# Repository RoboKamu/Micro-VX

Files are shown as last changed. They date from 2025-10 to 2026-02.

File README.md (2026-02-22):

<h1 align="center"> Micro-VX: Mini Audio Visualizer </h1>

<div align="center">
<i> Small portable STM32L4 based audio wave and FFT visualizer from electret microphone. This project started as an experiment to design my first PCB and explore the STM32L4 low-power MCU family. </i>
</div>

---

> This repository includes an extra project on the same board. The accelerometer visualization. That project was for expirementing with the module for future use. The main purpose for the board is for it to be used with the microphone, however a PCB error ment it had to be modified after assembly.
>

> Demo for expirimental Accelerometer Visualization: Github Video Link 
>
> Demo for FFT and Auido Wave Visualization: [Youtube Video Link](https://www.youtube.com/watch?v=JHZs5dUxs48)

<p align="center">
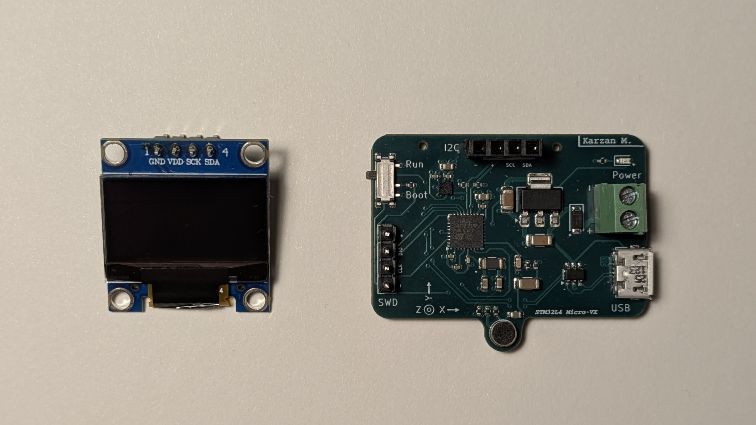
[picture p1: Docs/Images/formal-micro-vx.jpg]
Micro-VX board and OLED module
  
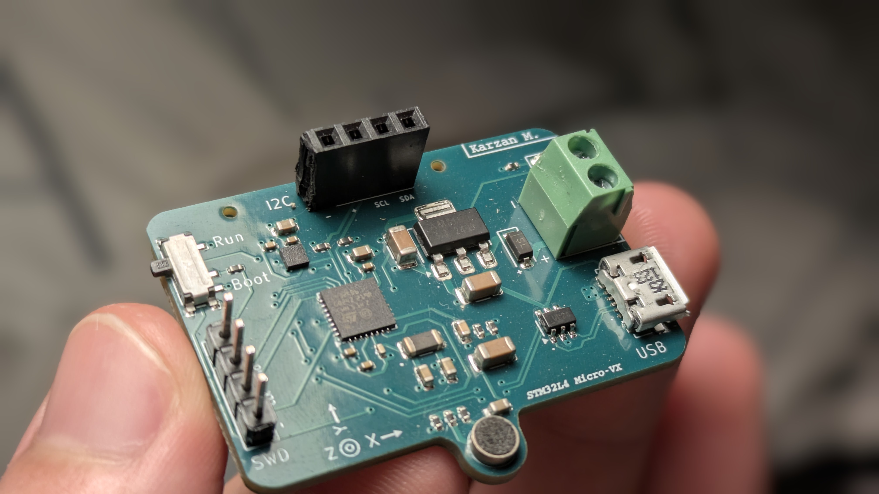
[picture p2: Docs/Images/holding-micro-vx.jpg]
Close-up of the assembled STM32L4 Micro-VX board
  
</p>

---

### 1. Project structure

#### 1.1 Hardware

All Kicad source files for Schematic and PCB files are in the hardware folder. Also including Gerber files and footprint placement (assembly) for direct manufacturing, in this case JLCPCB. 

There are 2 versions of the PCB, with one being modified after assembly.

* **Accelerometer visualization:** 
Original PCB according to the schematic. Utilizing the Accelerometer (3-axis LIS2DW12) and I2C pin headers for OLED display (SSD1306).

* **Audio analyzer:**
Modified after assembly (refer to hardware folder). The PCB used for the audio analysis with electret microphone (B4013AM423-093). Also utilizes the I2C pin headers for OLED display (SSD1306) and a mechanical switch to change program state. 

#### 1.2 Firmware

In the firmware folder you will see 2 projects: 

* **The STM32L4-LIS2DW12-Visual project in the STM32L4-Accelerometer-Visual folder:**
Visualizer for the cheap accelerometer I added to the PCB. The program just shows the X, Y and Z axis as well as temperature. Another detail is to measure VDDA, this is very useful for sampling with ADC on battery powered devices. Ensuring accurate scaling. 

* **STM32L4-FW :**
The main project is this audio wave and FFT visualizer. Depending on the mechanical switch state (read from EXTI callback) it can either be showing continous audio wave or the FFT representation of it. Includes TIMER2 peripheral for triggering ADC to sample microphone, DMA double buffering, and I2C protocol for OLED display. The MCU was programmed with a ST-LINK V2, developed in STM32cubeIDE with HAL, and used the ARM cmsis library for DSP applications. 

### 2. Hardware Architecture
The PCB includes ESD protection and reverse polarity protection. Safe to use even if both battery and USB is connected because of the schottcky diode "OR", and the onboard LDO ensures a stable voltage for the STM32.  

Refer to the hardware folder for more specific information about the post assembly modification. 

The STM32L4 was chosen because it is from the low power series and also includes FPU and DSP. Not much flash memory is needed here so the 32 KB flash size was chosen. 

### 3. Firmware Architecture

#### 3.1 STM32L4-FW 

The firmware is rather simple. Timer2 TRGO initiate a conversion with a sample rate of 50 kHz. The ADC uses 8x oversampling with 1 bit shift to compensate low gain on hardware. DMA double buffer is used so wave visualizer does not have to wait for the whole fft buffer fill up and instead waits for the halv-transfer-complete flag. The FFT uses the ARM CMSIS library and all visual functionality in this project is scaled to the OLED.

Improvements could be made in terms of optimization and scaling, but that is outside the scope of this project.  

#### 3.2 STM32L4-LIS2DW12-Visual project 
Timer 2 triggers ADC injected group conversion, the callback function then stores the raw ADC value to a variable and sets a data ready flag

Timer 15 triggers normal ADC conversion, the callback function then stores the raw ADC value to a variable and sets a data ready flag

VDDA conversion just uses the last non zero value to calculate the voltage based on the formula from the datasheet. 

For the accelerometer the Data-Ready interrupt pin is connected to EXTI pin on microcontroller, when state changes on the pin the microcontroller notes this with a flag to later use in the superloop. 

### 4. Future improvements
This project was more of a practise so no real futher improvements are scheduled. One critical mistake that was overlooked was the usage of the microphone. The schematic PDF in the hardware folder shows no usage of preamp stage, this led to a bad resolution being sampled. For the PCB routing there are also obvious improvements to be made, but that will not be noted here. Below is an example of a improved schematic. The microphone preamp stage was validated via LTSpice simulation.

[revised-sch.pdf](https://github.com/user-attachments/files/25467140/revised-sch.pdf)

revised-sch

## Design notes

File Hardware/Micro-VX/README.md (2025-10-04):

Some revision has been made to the PCB. 

The PCB is based on the original schematic for microphone. This works correctly with the Accelerometer project, however, not with the audio analyzer. For the latter, a resistor has to be desoldered and another added. This is mentioned in the microphone section in the schematic. 

Below is an image showing the crude modification to the left, and the original PCBA to the right.

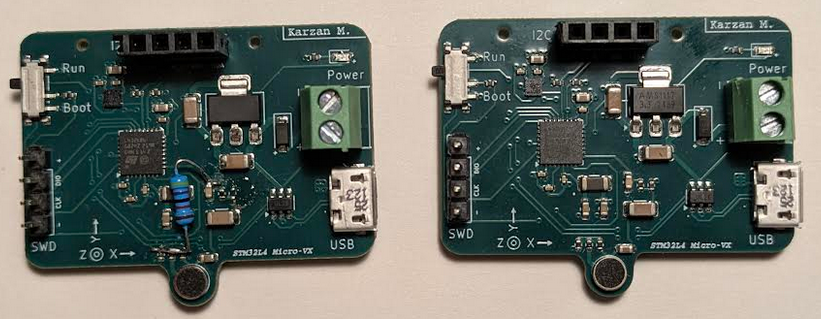
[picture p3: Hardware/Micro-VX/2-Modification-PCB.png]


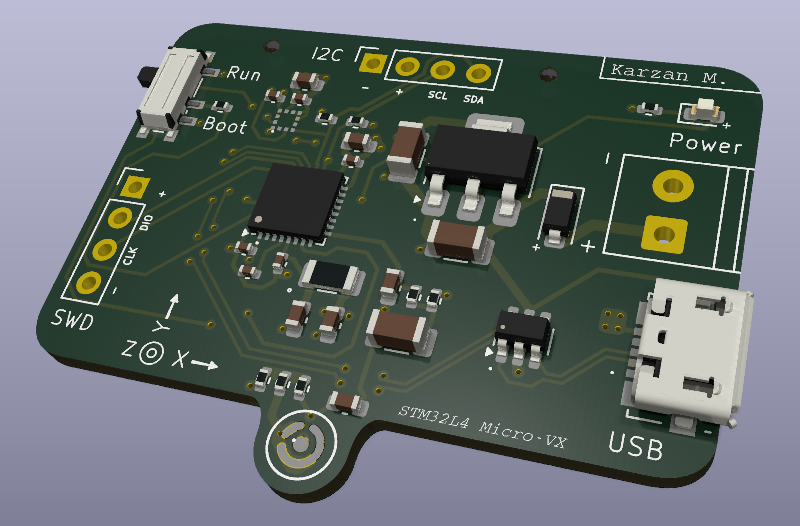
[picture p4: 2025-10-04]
Hardware/Micro-VX/1-Micro-VX.png

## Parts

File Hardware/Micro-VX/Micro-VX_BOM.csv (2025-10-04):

Reference | Qty | Value | Footprint | LCSC Part #
C1,C2,C7,C13,C14 | 5 | 100n | Capacitor_SMD:C_0402_1005Metric | C1525
C3,C12,C15 | 3 | 10u | Capacitor_SMD:C_0603_1608Metric | C19702
C4 | 1 | 10n | Capacitor_SMD:C_0402_1005Metric | C15195
C5,C6 | 2 | 1u | Capacitor_SMD:C_0603_1608Metric | C15849
C8,C9,C11 | 3 | 22u | Capacitor_SMD:C_1206_3216Metric | C12891
C10 | 1 | 22n | Capacitor_SMD:C_0603_1608Metric | C21122
D1 | 1 | LED | LED_SMD:LED_0603_1608Metric | C2286
D2 | 1 | D_Schottky | Diode_SMD:D_SOD-123 | C74179
FB1 | 1 | 120R | Fuse:Fuse_1206_3216Metric | C14709
J1 | 1 | USB_B_Micro | Connector_USB:USB_Micro-B_Molex_47346-0001 | C132560
J2 | 1 | Conn_01x04_Pin | Connector_PinHeader_2.54mm:PinHeader_1x04_P2.54mm_Vertical
J3 | 1 | Conn_01x04_Socket | Connector_PinSocket_2.54mm:PinSocket_1x04_P2.54mm_Vertical
J4 | 1 | Screw_Terminal_01x02 | TerminalBlock_Phoenix:TerminalBlock_Phoenix_PT-1,5-2-3.5-H_1x02_P3.50mm_Horizontal
MIC1 | 1 | B4013AM423-093 | MIC_B4013AM423-093:MIC-SMD_BD4.0_B4013AM423-093-1 | C233790
R1,R5,R6 | 3 | 10k | Resistor_SMD:R_0402_1005Metric | C25744
R2 | 1 | 1k5 | Resistor_SMD:R_0402_1005Metric | C25867
R3 | 1 | 100 | Resistor_SMD:R_0402_1005Metric | C25076
R4 | 1 | 47k | Resistor_SMD:R_0402_1005Metric | C25076
R7 | 1 | 2k2 | Resistor_SMD:R_0402_1005Metric | C25879
R8 | 1 | 1k2 | Resistor_SMD:R_0402_1005Metric | C25862
R9 | 1 | 2k | Resistor_SMD:R_0402_1005Metric | C4109
SW1 | 1 | SW_SPDT | Button_Switch_SMD:SW_SPDT_PCM12 | C97433
U1 | 1 | STM32L432KBU6 | Package_DFN_QFN:QFN-32-1EP_5x5mm_P0.5mm_EP3.45x3.45mm | C94784
U2 | 1 | AMS1117-3.3 | Package_TO_SOT_SMD:SOT-223-3_TabPin2 | C6186
U3 | 1 | ~ | LIS2DW12:LIS2DW12_LGA-12 | C189624
U4 | 1 | USBLC6-2SC6 | Package_TO_SOT_SMD:SOT-23-6 | C7519

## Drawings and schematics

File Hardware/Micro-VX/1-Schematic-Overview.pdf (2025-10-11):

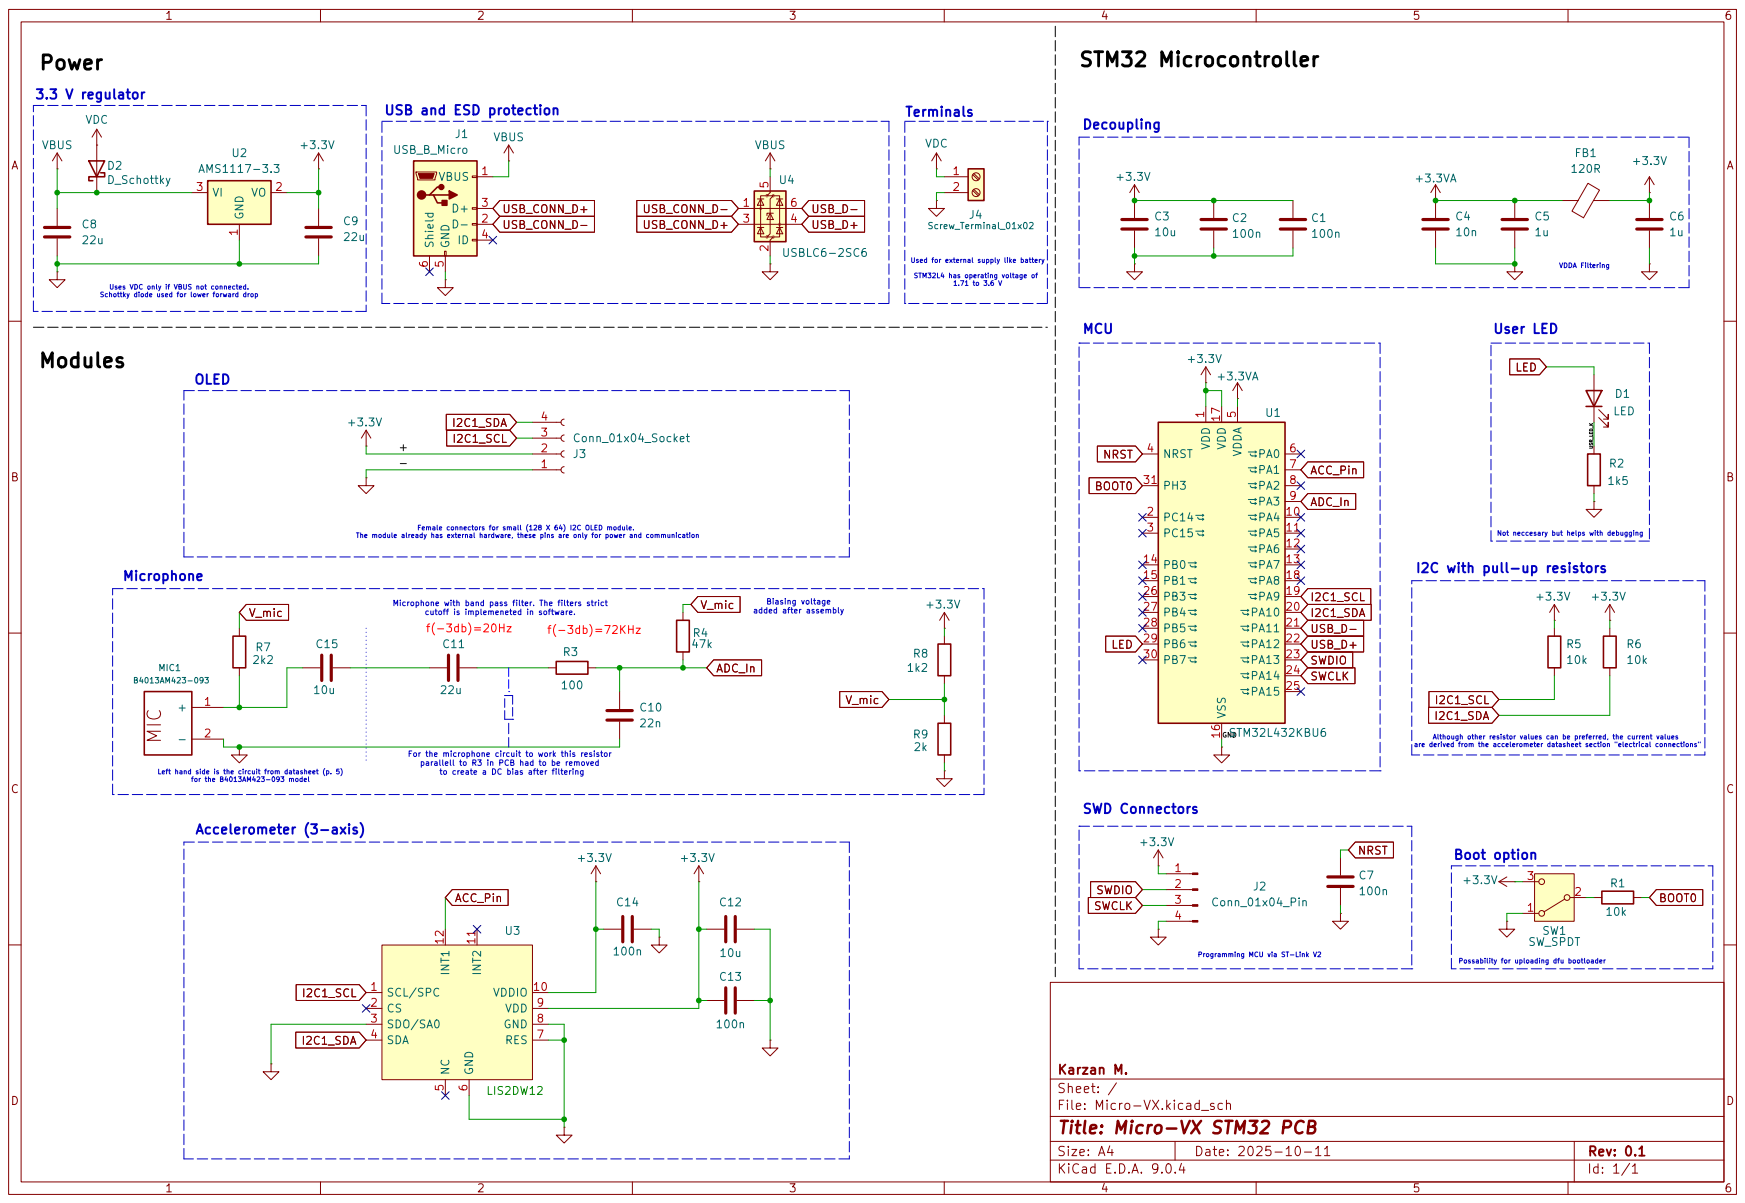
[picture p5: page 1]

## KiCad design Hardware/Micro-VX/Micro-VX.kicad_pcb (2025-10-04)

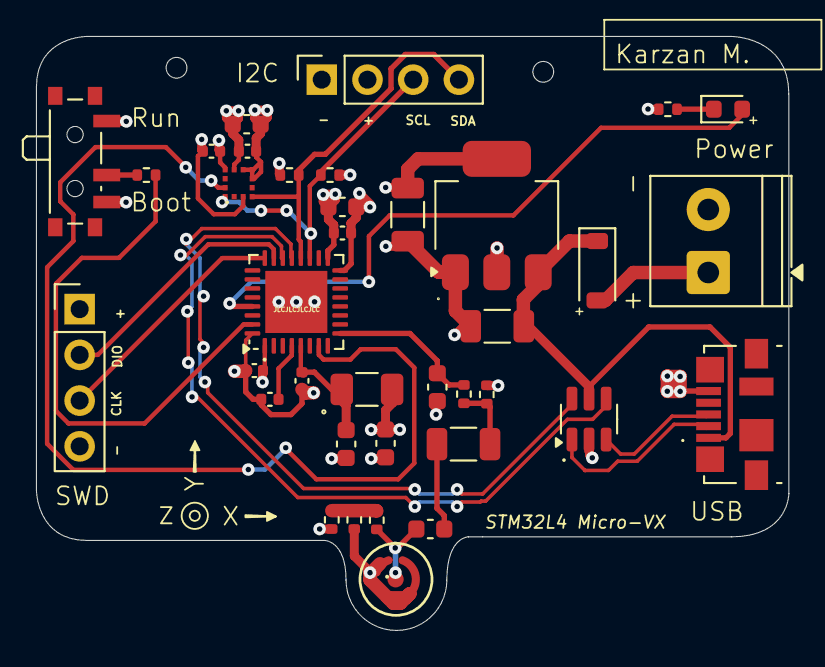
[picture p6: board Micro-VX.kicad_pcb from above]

Board: 4 copper layers, 41.8 x 33.0 mm, 37 parts (0 on the bottom side), 24 nets.

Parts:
C1, C2, C7, C13, C14: 100n; C_0402_1005Metric
C3, C12, C15: 10u; C_0603_1608Metric
C4: 10n; C_0402_1005Metric
C5, C6: 1u; C_0603_1608Metric
C8, C9, C11: 22u; C_1206_3216Metric
C10: 22n; C_0603_1608Metric
D1: LED; LED_0603_1608Metric
D2: D_Schottky; D_SOD-123
FB1: 120R; Fuse_1206_3216Metric
J1: USB_B_Micro; USB_Micro-B_Molex_47346-0001
J2: Conn_01x04_Pin; PinHeader_1x04_P2.54mm_Vertical
J3: Conn_01x04_Socket; PinSocket_1x04_P2.54mm_Vertical
J4: Screw_Terminal_01x02; TerminalBlock_Phoenix_PT-1,5-2-3.5-H_1x02_P3.50mm_Horizontal
MIC1: B4013AM423-093; MIC-SMD_BD4.0_B4013AM423-093-1
R1, R5, R6: 10k; R_0402_1005Metric
R2: 1k5; R_0402_1005Metric
R3: 100; R_0402_1005Metric
R4: 330; R_0402_1005Metric
R7: 2k2; R_0402_1005Metric
R8: 1200; R_0402_1005Metric
R9: 2000; R_0402_1005Metric
SW1: SW_SPDT; SW_SPDT_PCM12
U1: STM32L432KBU6; QFN-32-1EP_5x5mm_P0.5mm_EP3.45x3.45mm
U2: AMS1117-3.3; SOT-223-3_TabPin2
U3: LIS2DW12_LGA-12
U4: USBLC6-2SC6; SOT-23-6

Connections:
+3.3V: C1.1, C2.1, C3.1, C6.1, C9.1, C12.1, C13.1, C14.1, FB1.2, J2.1, J3.2, R5.1, R6.1, R8.1, SW1.3 (C), U1.1 (VDD), U1.17 (VDD), U2.2 (VO), U3.9 (VDD), U3.10 (VDDIO)
+3.3VA: C4.1, C5.1, FB1.1, U1.5 (VDDA)
/USR_LED_K: D1.1 (K), R2.1
ACC_Pin: U1.7 (PA1), U3.12 (INT1)
ADC_In: C10.1, R3.2, U1.9 (PA3)
BOOT0: R1.2, U1.31 (PH3)
GND: C1.2, C2.2, C3.2, C4.2, C5.2, C6.2, C7.2, C8.2, C9.2, C10.2, C12.2, C13.2, C14.2, J1.5 (GND), J2.4, J3.1, J4.2, MIC1.2 (-), R2.2, R4.1, R9.1, SW1.1 (A), U1.16 (VSS), U1.32 (VSS), U1.33 (VSS), U2.1 (GND), U3.3 (SDO/SA0), U3.6 (GND), U3.7 (RES), U3.8 (GND), U4.2 (GND)
I2C1_SCL: J3.3, R5.2, U1.19 (PA9), U3.1 (SCL/SPC)
I2C1_SDA: J3.4, R6.2, U1.20 (PA10), U3.4 (SDA)
LED: D1.2 (A), U1.29 (PB6)
NRST: C7.1, U1.4 (NRST)
unnamed: C11.1, C15.2
unnamed: C11.2, R3.1, R4.2
unnamed: C15.1, MIC1.1 (+), R7.1
unnamed: R1.1, SW1.2 (B)
SWCLK: J2.3, U1.24 (PA14)
SWDIO: J2.2, U1.23 (PA13)
USB_CONN_D+: J1.3 (D+), U4.3 (I/O2)
USB_CONN_D-: J1.2 (D-), U4.1 (I/O1)
USB_D+: U1.22 (PA12), U4.4 (I/O2)
USB_D-: U1.21 (PA11), U4.6 (I/O1)
VBUS: C8.1, D2.1 (K), J1.1 (VBUS), U2.3 (VI), U4.5 (VBUS)
VDC: D2.2 (A), J4.1
V_mic: R7.2, R8.2, R9.2

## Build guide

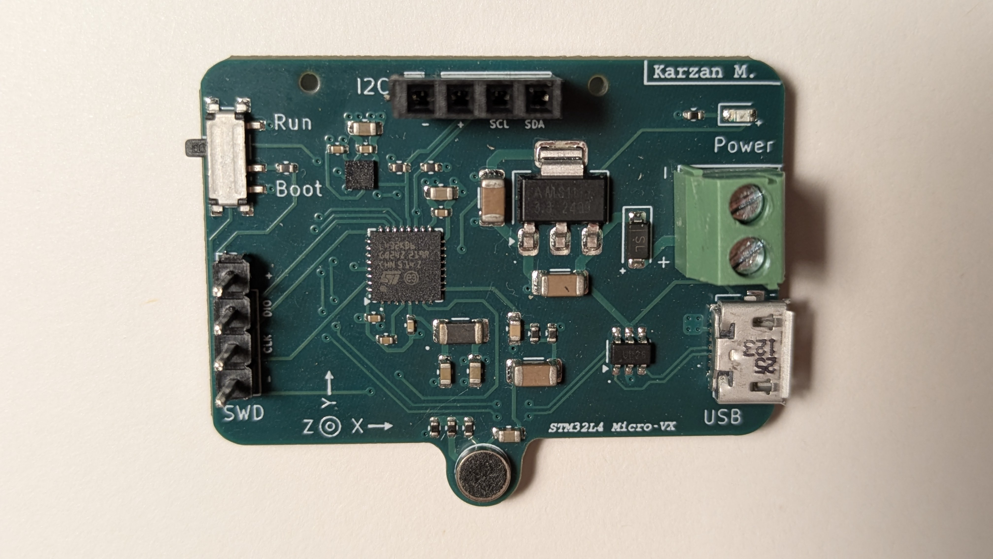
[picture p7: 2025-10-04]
Hardware/Micro-VX/2-Micro-VX-Assembly-Front.jpg

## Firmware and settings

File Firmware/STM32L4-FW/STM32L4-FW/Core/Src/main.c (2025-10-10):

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
/* Includes ------------------------------------------------------------------*/
#include "main.h"

/* USER CODE BEGIN Includes */

#include "ssd1306.h"        /* oled i2c module */
#include "ssd1306_fonts.h"  /* oled fonts */

#include "arm_math.h"

/* USER CODE END Includes */

/* USER CODE BEGIN PD */

/*
 * taken from stm32l4xx_ll_adc.h for definition of vrefint calibraion
 * ( datasheet p. 29, reference manual p. 311 )
 * Used for calculating the VDDA voltage
 */

#define BUFFER_LEN 							512 						/* total size of the dma buffer */
#define OLED_W								128							/* width of oled */
#define OLED_H								64							/* height of oled */

//#define DBG_MODE
#ifdef DBG_MODE
#include <stdarg.h>         /* varadic functions */
#include <string.h>         /* dbg include for uart print */
#include <stdio.h>
#endif

/* USER CODE END PD */

ADC_HandleTypeDef hadc1;
DMA_HandleTypeDef hdma_adc1;

I2C_HandleTypeDef hi2c1;

TIM_HandleTypeDef htim15;

/* USER CODE BEGIN PV */

volatile uint8_t dma_ftf_flag = 0;
volatile uint8_t dma_htf_flag = 0;

static uint16_t samples[BUFFER_LEN];

#define N 				BUFFER_LEN					/* used for FFT array and looping */
#define SAMPLE_RATE		50000.0f					/* effective sampling freq (64 Mhz / 640/2) */

float fft_buf_in[N];
float fft_buf_out[N];
arm_rfft_fast_instance_f32 fft_handler;

volatile GPIO_PinState state;

/* USER CODE END PV */

void SystemClock_Config(void);
static void MX_GPIO_Init(void);
static void MX_DMA_Init(void);
static void MX_ADC1_Init(void);
static void MX_I2C1_Init(void);
static void MX_TIM15_Init(void);
/* USER CODE BEGIN PFP */

#if defined(DBG_MODE)
static void oled_print(uint8_t x, uint8_t y, const SSD1306_Font_t Font,
		SSD1306_COLOR color, const char *s, ...);
#endif

static void run_audio_visualizer(uint8_t cycle);
static void run_fft_visualizer();

/* USER CODE END PFP */

/* USER CODE BEGIN 0 */

void HAL_GPIO_EXTI_Callback(uint16_t GPIO_Pin) {

	if (GPIO_Pin == SWITCH_EXTI_Pin) {

		/* Update for new state */
		state = HAL_GPIO_ReadPin(SWITCH_EXTI_GPIO_Port, SWITCH_EXTI_Pin);

	}

}

void HAL_ADC_ConvCpltCallback(ADC_HandleTypeDef *hadc) {

	if (hadc->Instance == ADC1) {

		dma_ftf_flag = 1;
		HAL_GPIO_TogglePin(LED_GPIO_Port, LED_Pin);

	}

}

void HAL_ADC_ConvHalfCpltCallback(ADC_HandleTypeDef *hadc) {

	if (hadc->Instance == ADC1) {

		dma_htf_flag = 1;
		HAL_GPIO_TogglePin(LED_GPIO_Port, LED_Pin);

	}

}

/* USER CODE END 0 */

/**
  * @brief  The application entry point.
  * @retval int
  */
int main(void)
{

  /* MCU Configuration--------------------------------------------------------*/

  /* Reset of all peripherals, Initializes the Flash interface and the Systick. */
  HAL_Init();

  /* Configure the system clock */
  SystemClock_Config();

  /* Initialize all configured peripherals */
  MX_GPIO_Init();
  MX_DMA_Init();
  MX_ADC1_Init();
  MX_I2C1_Init();
  MX_TIM15_Init();
  /* USER CODE BEGIN 2 */

	/* initialize FFT */
	arm_rfft_fast_init_f32(&fft_handler, N);

	ssd1306_Init();

	/* calibrate and start ADC with interrupts */

	if (HAL_ADCEx_Calibration_Start(&hadc1, ADC_SINGLE_ENDED) != HAL_OK)
		Error_Handler();

	if (HAL_ADC_Start_DMA(&hadc1, samples, BUFFER_LEN) != HAL_OK)
		Error_Handler();

	if (HAL_TIM_Base_Start_IT(&htim15) != HAL_OK)
		Error_Handler();

	ssd1306_Fill(Black);
	ssd1306_UpdateScreen();

  /* USER CODE END 2 */

  /* Infinite loop */
  /* USER CODE BEGIN WHILE */
	while (1) {

		if (dma_htf_flag) {
			dma_htf_flag = 0;
			for (uint16_t i = 0; i < N / 2; i++) {
				fft_buf_in[i] = (float) samples[i];
			}
			if (state == GPIO_PIN_RESET)
				run_audio_visualizer(0);
		}

		if (dma_ftf_flag) {
			dma_ftf_flag = 0;
			for (uint16_t i = N / 2; i < N; i++) {
				fft_buf_in[i] = (float) samples[i];
			}

			if (state == GPIO_PIN_SET)
				run_fft_visualizer();
			else
				run_audio_visualizer(1);
		}

    /* USER CODE END WHILE */

    /* USER CODE BEGIN 3 */
	}
  /* USER CODE END 3 */
}

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
/* USER CODE BEGIN 4 */

#ifdef DBG_MODE
/**
 * @brief wrapper for printing string to OLED
 */
static void oled_print(uint8_t x, uint8_t y, const SSD1306_Font_t Font,
		SSD1306_COLOR color, const char *s, ...) {

	/*
	 * This is a varadic function that wraps the printing sequence to the OLED.
	 * Can then be used like printf after defining location, font and color.
	 * More on varadic functions here: https://man7.org/linux/man-pages/man3/stdarg.3.html
	 * More on vsnprintf here: https://man7.org/linux/man-pages/man3/vsnprintf.3.html
	 */

	int n = 0;
	char buffer[20];
	if (strlen(s) > 20)
		return;

	va_list args;

	va_start(args, s);
	n = vsnprintf(buffer, sizeof(buffer), s, args);
	va_end(args);

	if (n < 0)
		return;

	ssd1306_SetCursor(x, y);
	ssd1306_WriteString(buffer, Font, color);

}
#endif

/**
 * audio analyzer, prints first 128 samples on oled based on cycle (first or second half of dma)
 * Uses relative scaling for better display if values are above threshold
 */
static void run_audio_visualizer(uint8_t cycle) {

	/* identify if its first or second half of buffer to visualize */
	uint16_t start_idx, len;
	if (cycle == 0) {
		start_idx = 0;
		len = BUFFER_LEN / 4;
	} else if (cycle == 1) {
		start_idx = BUFFER_LEN / 2;
		len = BUFFER_LEN - BUFFER_LEN / 4;
	} else {
		return;
	}

	ssd1306_Fill(Black);

	/* calculate mean */
	float sum = 0.0f, max = 1.0f;
	for (uint16_t i = start_idx; i < len; i++) {
		if (fft_buf_in[i] > max)
			max = fft_buf_in[i];
		sum += fft_buf_in[i];
	}
	float mean = sum / ((float) (len - start_idx));

	/* calculate variables for centering and scaling the wave */
	float sum_square = 0.0f;
	for (uint16_t i = start_idx; i < len; i++) {
		float v = fft_buf_in[i] - mean;
		sum_square += v * v;
	}
	float mean_square = sum_square / (float)(len - start_idx);
	float rms = sqrtf(mean_square);

	const float rms_to_peak = 1.6f;      /* peak ≈ 1.4–2.0 × RMS; not perfect sine */
	const float rms_thresh  = 2.0f;      /* below this, treat as silence (in ADC LSBs) */

	float scale = (rms > rms_thresh) ? (15.0f / (rms_to_peak * rms))
									 : (15.0f / 2048.0f);

	/* display 128 samples, scaled to oled  */
	uint8_t x_px = 0;
	for (uint16_t i = start_idx; i < len; i++) {
		float y = (OLED_H / 2 - 1) - (fft_buf_in[i] - mean) * scale;
		if (y >= OLED_H) y = 63;
		if (y < 0) y = 0;
		ssd1306_DrawPixel(x_px++, (uint8_t) (y + 0.5), White);
	}

	ssd1306_UpdateScreen();
}

/**
 * @breif showing FFT visualizer on OLED
 *
 */
static void run_fft_visualizer() {

	ssd1306_Fill(Black);

	/* calculate the mean in the fft buffer */
	float sum = 0;
	for (uint16_t i = 0; i < N; i++)
		sum += fft_buf_in[i];
	float mean = (float) sum / (float) N;

	/* remove DC offset */
	for (uint16_t i = 0; i < N; i++) {
		float hann = 0.5 * (1 - cos(2 * PI * i / (N - 1))); /* hann window multiplier */
		float val = (float) fft_buf_in[i] - mean;
		fft_buf_in[i] = hann * val;
	}

	arm_rfft_fast_f32(&fft_handler, fft_buf_in, fft_buf_out, 0);

//	float max = 1.0f;
	float mags[N / 2];

	float scale = 63.0f / 2048.0f; /* scale factor for magnitudes to oled */

	uint16_t bin_index = 0; /* keep track of the index for fft bin number in loop */
	for (uint16_t i = 1; i < N; i += 2) {
		/* calculate the magnitude of the bin */
		float re = fft_buf_out[i] * scale;
		float im = fft_buf_out[i + 1] * scale;
		mags[bin_index] = sqrtf(re * re + im * im);
//		if (max < mags[bin_index]) {
//			max = mags[bin_index];
//			peakHz = (uint16_t) ((float)bin_index * SAMPLE_RATE / ((float)N));
//		}
		bin_index++;
	}

	/* cap the display width to desired freq (16 kHz in this case) */
	float desired_max_freq = 16000.0 / (SAMPLE_RATE / (float) N);
	float bin_scale = OLED_W / desired_max_freq;

	/* display the transform */
	for (uint16_t i = 1; i < N; i++) {
		float mag = mags[i];
		if (mag < 2) mag = 0;

		mag = mag >= 63.0 ? 63 : mag;
		mag = mag < 0 ? 0 : mag;

		float x = ((float) i) * bin_scale;
		if (x >= OLED_W) break;

		ssd1306_Line((uint8_t)x, 63, (uint8_t)x, 62-(uint8_t)mag, White);
//		ssd1306_DrawPixel((uint8_t) x, 63 - (uint8_t) mag, White);
	}

//	oled_print(0, 32, Font_7x10, White, "freq= %u", peakHz);
	ssd1306_UpdateScreen();
}

/* USER CODE END 4 */
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


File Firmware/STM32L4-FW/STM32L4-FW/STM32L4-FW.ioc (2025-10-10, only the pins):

Mcu.UserName=STM32L432KBUx
PA10.Signal=I2C1_SDA
PA3.GPIO_Label=MIC_IN
PA3.Signal=ADCx_IN8
PA9.Signal=I2C1_SCL
PB6.GPIO_Label=LED
PB6.Signal=GPIO_Output
PH3-BOOT0.GPIO_Label=SWITCH_EXTI
PH3-BOOT0.Signal=GPXTI3

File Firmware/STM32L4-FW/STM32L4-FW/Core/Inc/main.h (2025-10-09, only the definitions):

#define MIC_IN_Pin GPIO_PIN_3
#define MIC_IN_GPIO_Port GPIOA
#define LED_Pin GPIO_PIN_6
#define LED_GPIO_Port GPIOB
#define SWITCH_EXTI_Pin GPIO_PIN_3
#define SWITCH_EXTI_GPIO_Port GPIOH
#define SWITCH_EXTI_EXTI_IRQn EXTI3_IRQn

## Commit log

2025-10-04 Intial commit
    [Micro-VX-B_Cu.gbr, Micro-VX-B_Mask.gbr, Micro-VX-B_Paste.gbr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]
2025-10-10 Change FFT scaling and use lines instead of bars
    Also change audio wave to scale with RMS and increase I2C to fast mode (400 kHz)
2025-10-11 update hardware date
    [Micro-VX.kicad_sch]

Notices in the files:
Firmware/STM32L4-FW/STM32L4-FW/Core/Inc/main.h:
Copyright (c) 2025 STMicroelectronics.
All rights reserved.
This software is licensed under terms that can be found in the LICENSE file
